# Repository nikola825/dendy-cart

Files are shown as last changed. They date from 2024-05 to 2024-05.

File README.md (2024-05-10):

# Programmable cartridge for Dendy-style consoles

Programmable PLD-based cartrige for Dendy-like consoles.

## Features
1. 1MB of SRAM for use as PRG ROM or PRG RAM
2. 1MB of SRAM for use as CHR ROM or CHR RAM
3. Atmel ATF1508 CPLD for glue logic, mapper implementation and flashing
4. LM66100 and a CR2032 battery holder to allow RAM to act as non-volatile storage
5. JTAG header for CPLD flashing

## Tooling
Makefile and linker configuration for writing programs
Pattern table generator script to generate pattern table contents from bitmaps

## Repo contents
cart - Kicad project and BOM
verilog - Verilog code for the ATF1508 CPLD
6502_development/demo_program - demo code for writing programs
6502_development/bmptransform - python script to generate pattern table contents from bmp images

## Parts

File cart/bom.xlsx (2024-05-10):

 |  |  | xxxx xxxx xxxxx xxPCS BOM (Sample Bill of Materials)
Item # | *Designator | *Qty | Manufacturer | *Mfg Part # | Description / Value | *Package/Footprint | Type | Your Instructions / Notes
1 | C1 | 1 | Don’t care | Don’t care | CAP CER 33pF 16V C0G 0603 | 0603 | SMD | Don’t care about model/manufacturer, just make sure it fits description
2 | C2, C3, C4, C5, C8, C9 | 6 | Don’t care | Don’t care | CAP CER 100nF 16V X7R 0603 | 0603 | SMD | Don’t care about model/manufacturer, just make sure it fits description
3 | C6, C7 | 2 | Don’t care | Don’t care | CAP CER 1uF 16V X7R 0805 | 0805 | SMD | Don’t care about model/manufacturer, just make sure it fits description
4 | D1, D2, D3, D4, D5, D6, D7, D8 | 8 | Foshan NationStar | NCD0603R1 | LED SMD Red 2V 20ma 0603 | 0603 | SMD
5 | R1, R4, R5, R6, R7, R8, R11, R18 | 8 | Don’t care | Don’t care | RES 10K OHM 0.1W 1% 0603 SMD | 0603 | SMD | Don’t care about model/manufacturer, just make sure it fits description
6 | R2, R3, R9, R10, R12, R13, R14, R15, R16 | 9 | Don’t care | Don’t care | RES 1K OHM 0.1W 1% 0603 SMD | 0603 | SMD | Don’t care about model/manufacturer, just make sure it fits description
7 | U1, U2 | 2 | Alliance Memory | AS6C8008-55ZIN | SRAM - Asynchronous Memory IC 8Mbit Parallel 55 ns 44-TSOP II | 44pin TSOP II | SMD
8 | U4 | 1 | Texas Instruments | SN74HCT00PWR | IC GATE NAND 4CH 2-INP 14TSSOP | 14-TSSOP | SMD
9 | U5 | 1 | Texas Instruments | SN74HCT573PWR | D-Type Transparent Latch 1 Channel 8:8 IC Tri-State 20-TSSOP | 20-TSSOP | SMD
10 | U6, U7 | 2 | Texas Instruments | LM66100DCKT | OR Controller P-Channel 1:1 SC-70-6 | 6-TSSOP, SC-88, SOT-363 | SMD
11 | U8 | 1 | Microchip Technology | ATF1508AS-7AX100 | TQFP-100(14x14) Programmable Logic Device CPLD | TQFP-100(14x14) | SMD
12 | J5/J3 | 1 | Sullins | ECC30MMVD-S189/4548247 | 60 Position Male Connector Fits Female Edgecards Gold 0.100" (2.54mm) | TH 2.54x5.08 | TH
Need a quick and accurante quote? Need an efficient production? Please read SMT Ordering Necessary Files & Info in 1 minute. Thank you very much! (https://www.pcbway.com/smt_ordering_guide.html)
Click for Instructions on How to Create a BOM (https://www.pcbway.com/blog/PCB_Assembly/How_to_Build_a_BOM__Bill_Of_Materials_.html)

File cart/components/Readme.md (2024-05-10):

## Extra symbols
Symbol packages obtained from https://ultralibrarian.com

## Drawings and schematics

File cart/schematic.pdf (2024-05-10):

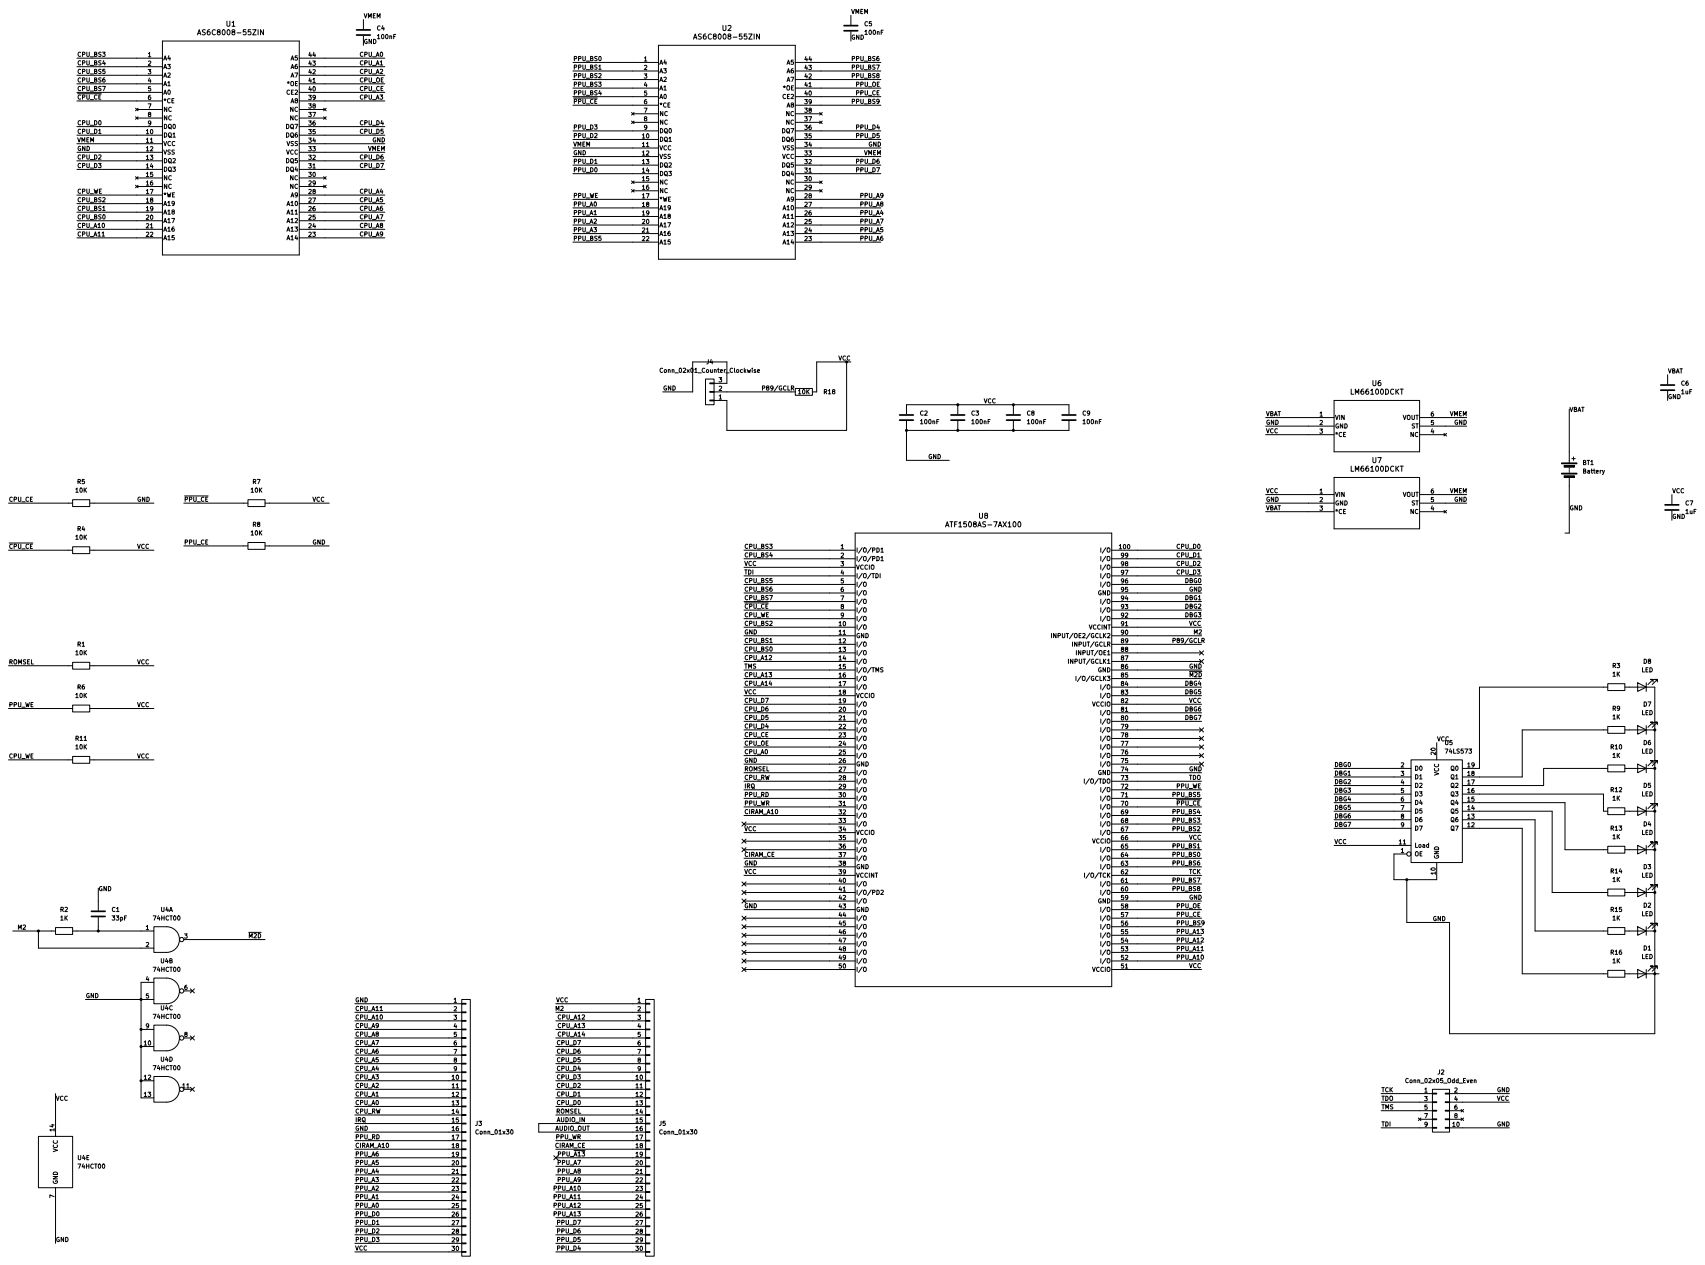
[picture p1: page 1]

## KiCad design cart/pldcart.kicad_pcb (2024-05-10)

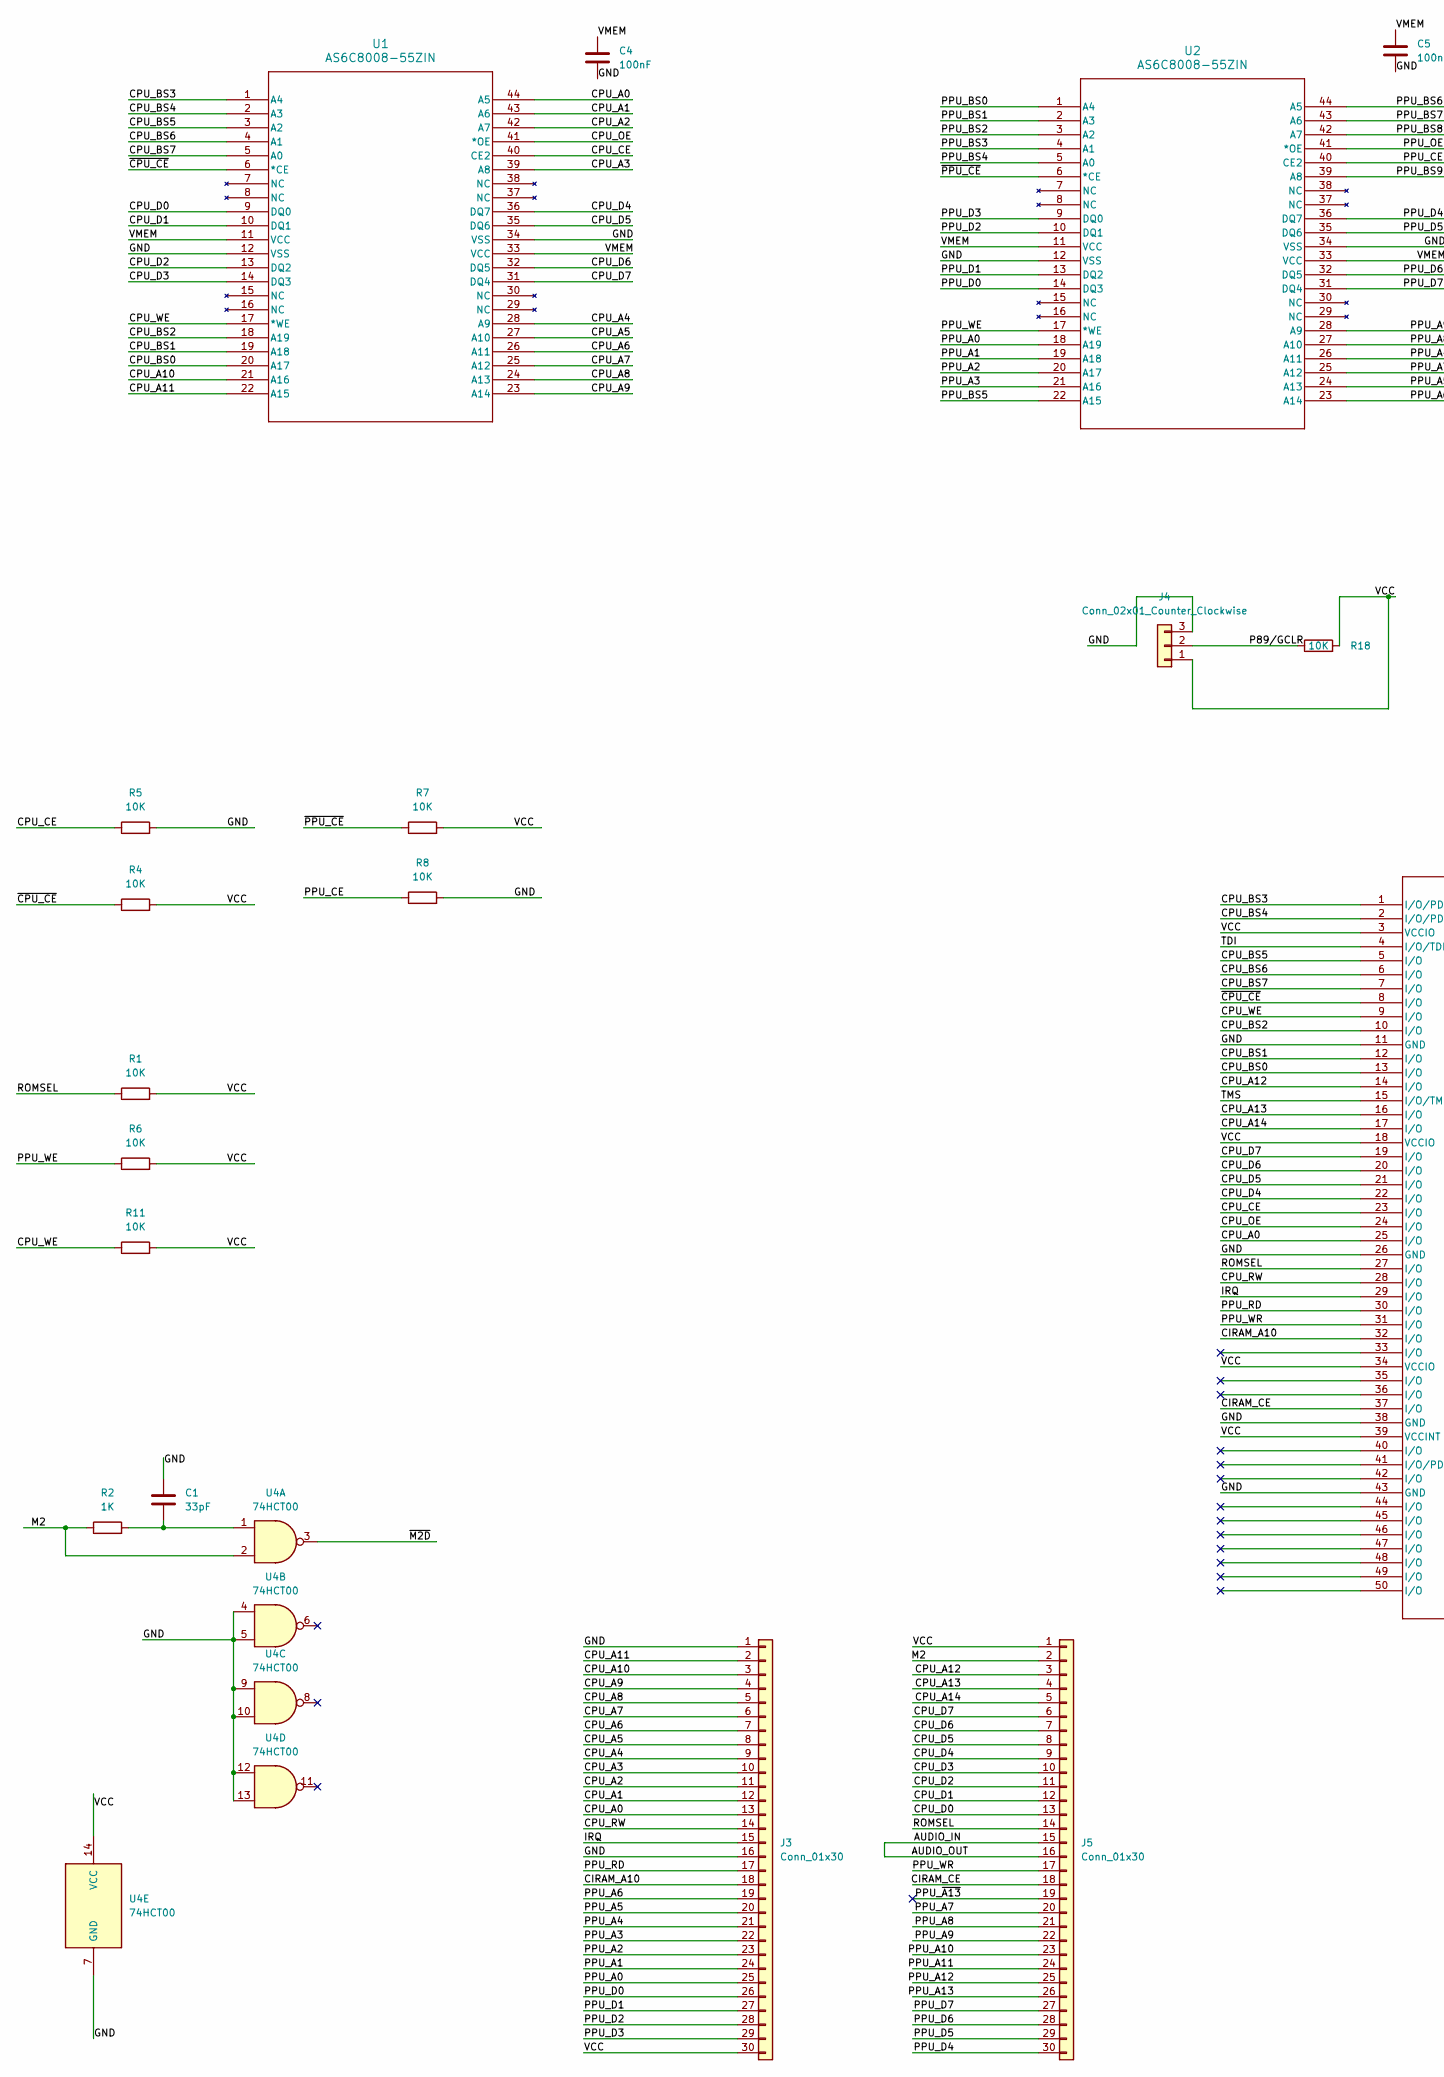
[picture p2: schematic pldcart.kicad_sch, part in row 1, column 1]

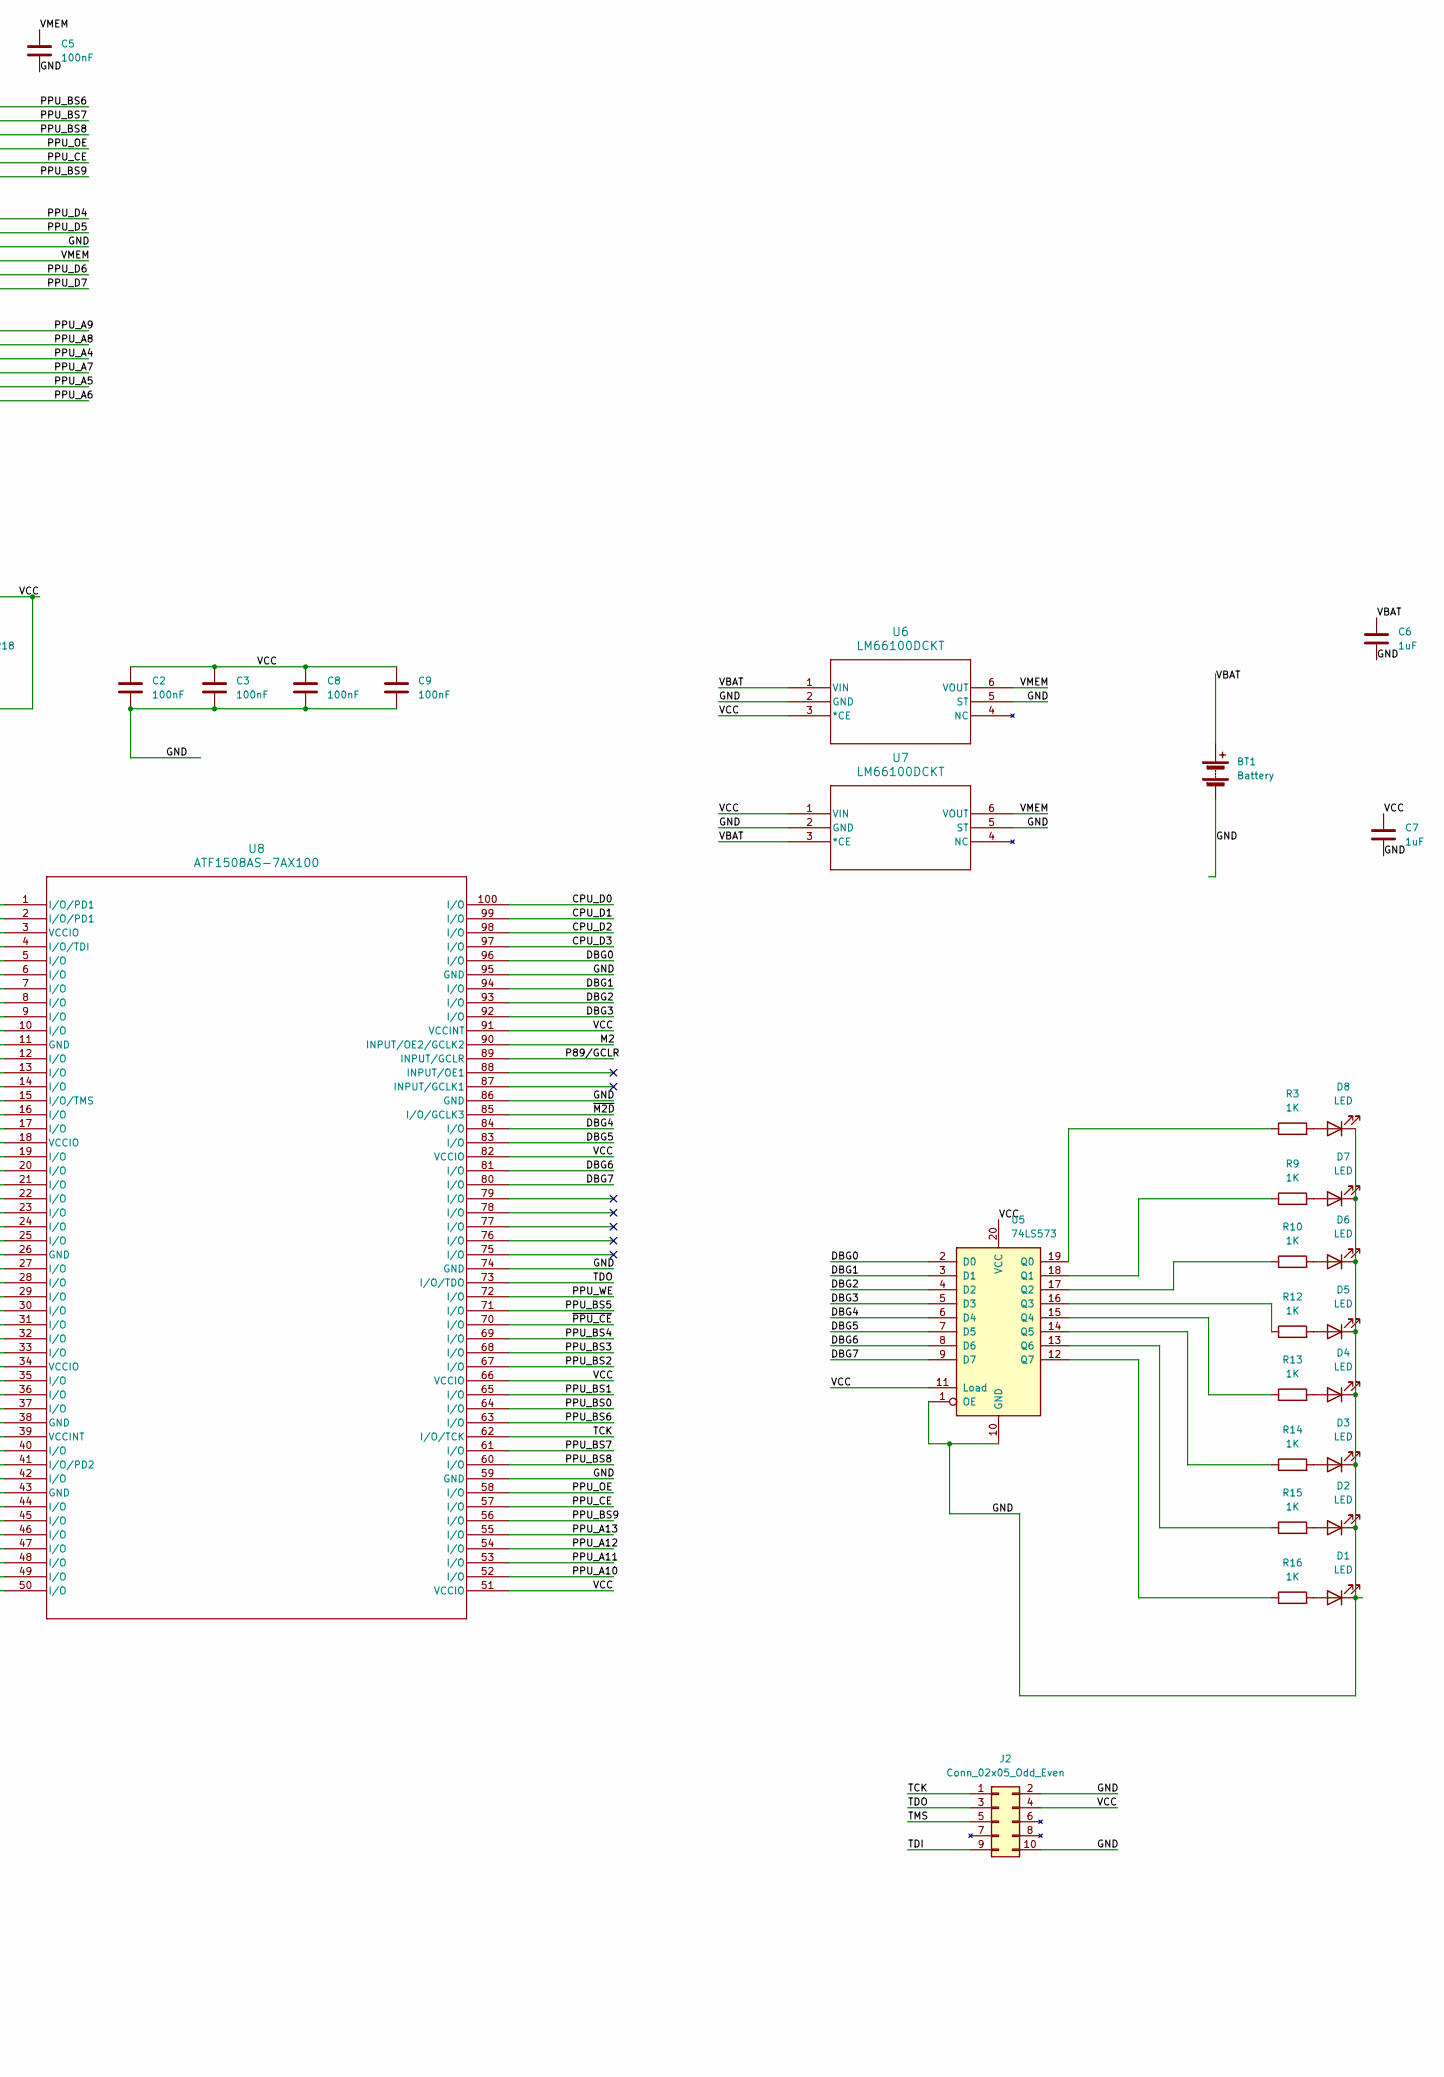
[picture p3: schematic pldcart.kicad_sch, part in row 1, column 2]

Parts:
BT1: Battery; BatteryHolder_Keystone_103_1x20mm
C1: 33pF; C_0603_1608Metric
C2, C3, C4, C5, C8, C9: 100nF; C_0603_1608Metric
C6, C7: 1uF; C_0805_2012Metric
D1, D2, D3, D4, D5, D6, D7, D8: LED; LED_0603_1608Metric
J2: Conn_02x05_Odd_Even; PinHeader_2x05_P2.54mm_Vertical
J3, J5: Conn_01x30; PinHeader_1x30_P2.54mm_Vertical
J4: Conn_02x01_Counter_Clockwise; PinHeader_1x03_P2.54mm_Vertical
R1, R4, R5, R6, R7, R8, R11, R18: 10K; R_0603_1608Metric
R2, R3, R9, R10, R12, R13, R14, R15, R16: 1K; R_0603_1608Metric
U1, U2: AS6C8008-55ZIN; TSOP-II-44_10.16x18.41mm_P0.8mm
U4: 74HCT00; TSSOP-14_4.4x5mm_P0.65mm
U5: 74LS573; TSSOP-20_4.4x6.5mm_P0.65mm
U6, U7: LM66100DCKT; SOT-363_SC-70-6
U8: ATF1508AS-7AX100; TQFP-100_14x14mm_P0.5mm

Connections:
/AUDIO_IN: J5.15, J5.16
/CIRAM_A10: J3.18, U8.32 (I/O)
/CIRAM_CE: J5.18, U8.37 (I/O)
/CPU_A0: J3.13, U1.44 (A5), U8.25 (I/O)
/CPU_A1: J3.12, U1.43 (A6)
/CPU_A2: J3.11, U1.42 (A7)
/CPU_A3: J3.10, U1.39 (A8)
/CPU_A4: J3.9, U1.28 (A9)
/CPU_A5: J3.8, U1.27 (A10)
/CPU_A6: J3.7, U1.26 (A11)
/CPU_A7: J3.6, U1.25 (A12)
/CPU_A8: J3.5, U1.24 (A13)
/CPU_A9: J3.4, U1.23 (A14)
/CPU_A10: J3.3, U1.21 (A16)
/CPU_A11: J3.2, U1.22 (A15)
/CPU_A12: J5.3, U8.14 (I/O)
/CPU_A13: J5.4, U8.16 (I/O)
/CPU_A14: J5.5, U8.17 (I/O)
/CPU_BS0: U1.20 (A17), U8.13 (I/O)
/CPU_BS1: U1.19 (A18), U8.12 (I/O)
/CPU_BS2: U1.18 (A19), U8.10 (I/O)
/CPU_BS3: U1.1 (A4), U8.1 (I/O/PD1)
/CPU_BS4: U1.2 (A3), U8.2 (I/O/PD1)
/CPU_BS5: U1.3 (A2), U8.5 (I/O)
/CPU_BS6: U1.4 (A1), U8.6 (I/O)
/CPU_BS7: U1.5 (A0), U8.7 (I/O)
/CPU_CE: R5.1, U1.40 (CE2), U8.23 (I/O)
/CPU_D0: J5.13, U1.9 (DQ0), U8.100 (I/O)
/CPU_D1: J5.12, U1.10 (DQ1), U8.99 (I/O)
/CPU_D2: J5.11, U1.13 (DQ2), U8.98 (I/O)
/CPU_D3: J5.10, U1.14 (DQ3), U8.97 (I/O)
/CPU_D4: J5.9, U1.36 (DQ7), U8.22 (I/O)
/CPU_D5: J5.8, U1.35 (DQ6), U8.21 (I/O)
/CPU_D6: J5.7, U1.32 (DQ5), U8.20 (I/O)
/CPU_D7: J5.6, U1.31 (DQ4), U8.19 (I/O)
/CPU_OE: U1.41 (*OE), U8.24 (I/O)
/CPU_RW: J3.14, U8.28 (I/O)
/CPU_WE: R11.1, U1.17 (*WE), U8.9 (I/O)
/DBG0: U5.2 (D0), U8.96 (I/O)
/DBG1: U5.3 (D1), U8.94 (I/O)
/DBG2: U5.4 (D2), U8.93 (I/O)
/DBG3: U5.5 (D3), U8.92 (I/O)
/DBG4: U5.6 (D4), U8.84 (I/O)
/DBG5: U5.7 (D5), U8.83 (I/O)
/DBG6: U5.8 (D6), U8.81 (I/O)
/DBG7: U5.9 (D7), U8.80 (I/O)
/GND: BT1.2 (-), C1.1, C2.2, C3.2, C4.2, C5.2, C6.2, C7.2, C8.2, C9.2, D1.1 (K), D2.1 (K), D3.1 (K), D4.1 (K), D5.1 (K), D6.1 (K), D7.1 (K), D8.1 (K), J2.2, J2.10, J3.1, J3.16, J4.3, R5.2, R8.2, U1.12 (VSS), U1.34 (VSS), U2.12 (VSS), U2.34 (VSS), U4.4, U4.5, U4.7 (GND), U4.9, U4.10, U4.12, U4.13, U5.1 (OE), U5.10 (GND), U6.2 (GND), U6.5 (ST), U7.2 (GND), U7.5 (ST), U8.11 (GND), U8.26 (GND), U8.38 (GND), U8.43 (GND), U8.59 (GND), U8.74 (GND), U8.86 (GND), U8.95 (GND)
/IRQ: J3.15, U8.29 (I/O)
/M2: J5.2, R2.1, U4.2, U8.90 (INPUT/OE2/GCLK2)
/P89/GCLR: J4.2, R18.1, U8.89 (INPUT/GCLR)
/PPU_A0: J3.25, U2.18 (A19)
/PPU_A1: J3.24, U2.19 (A18)
/PPU_A2: J3.23, U2.20 (A17)
/PPU_A3: J3.22, U2.21 (A16)
/PPU_A4: J3.21, U2.26 (A11)
/PPU_A5: J3.20, U2.24 (A13)
/PPU_A6: J3.19, U2.23 (A14)
/PPU_A7: J5.20, U2.25 (A12)
/PPU_A8: J5.21, U2.27 (A10)
/PPU_A9: J5.22, U2.28 (A9)
/PPU_A10: J5.23, U8.52 (I/O)
/PPU_A11: J5.24, U8.53 (I/O)
/PPU_A12: J5.25, U8.54 (I/O)
/PPU_A13: J5.26, U8.55 (I/O)
/PPU_BS0: U2.1 (A4), U8.64 (I/O)
/PPU_BS1: U2.2 (A3), U8.65 (I/O)
/PPU_BS2: U2.3 (A2), U8.67 (I/O)
/PPU_BS3: U2.4 (A1), U8.68 (I/O)
/PPU_BS4: U2.5 (A0), U8.69 (I/O)
/PPU_BS5: U2.22 (A15), U8.71 (I/O)
/PPU_BS6: U2.44 (A5), U8.63 (I/O)
/PPU_BS7: U2.43 (A6), U8.61 (I/O)
/PPU_BS8: U2.42 (A7), U8.60 (I/O)
/PPU_BS9: U2.39 (A8), U8.56 (I/O)
/PPU_CE: R8.1, U2.40 (CE2), U8.57 (I/O)
/PPU_D0: J3.26, U2.14 (DQ3)
/PPU_D1: J3.27, U2.13 (DQ2)
/PPU_D2: J3.28, U2.10 (DQ1)
/PPU_D3: J3.29, U2.9 (DQ0)
/PPU_D4: J5.30, U2.36 (DQ7)
/PPU_D5: J5.29, U2.35 (DQ6)
/PPU_D6: J5.28, U2.32 (DQ5)
/PPU_D7: J5.27, U2.31 (DQ4)
/PPU_OE: U2.41 (*OE), U8.58 (I/O)
/PPU_RD: J3.17, U8.30 (I/O)
/PPU_WE: R6.1, U2.17 (*WE), U8.72 (I/O)
/PPU_WR: J5.17, U8.31 (I/O)
/PPU_~A13: J5.19
/ROMSEL: J5.14, R1.1, U8.27 (I/O)
/TCK: J2.1, U8.62 (I/O/TCK)
/TDI: J2.9, U8.4 (I/O/TDI)
/TDO: J2.3, U8.73 (I/O/TDO)
/TMS: J2.5, U8.15 (I/O/TMS)
/VBAT: BT1.1 (+), C6.1, U6.1 (VIN), U7.3 (*CE)
/VCC: C2.1, C3.1, C7.1, C8.1, C9.1, J2.4, J3.30, J4.1, J5.1, R1.2, R4.2, R6.2, R7.2, R11.2, R18.2, U4.14 (VCC), U5.11 (Load), U5.20 (VCC), U6.3 (*CE), U7.1 (VIN), U8.3 (VCCIO), U8.18 (VCCIO), U8.34 (VCCIO), U8.39 (VCCINT), U8.51 (VCCIO), U8.66 (VCCIO), U8.82 (VCCIO), U8.91 (VCCINT)
/VMEM: C4.1, C5.1, U1.11 (VCC), U1.33 (VCC), U2.11 (VCC), U2.33 (VCC), U6.6 (VOUT), U7.6 (VOUT)
/~CPU_CE: R4.1, U1.6 (*CE), U8.8 (I/O)
/~M2D: U4.3, U8.85 (I/O/GCLK3)
/~PPU_CE: R7.1, U2.6 (*CE), U8.70 (I/O)
unnamed: C1.2, R2.2, U4.1
unnamed: D1.2 (A), R16.2
unnamed: D2.2 (A), R15.2
unnamed: D3.2 (A), R14.2
unnamed: D4.2 (A), R13.2
unnamed: D5.2 (A), R12.2
unnamed: D6.2 (A), R10.2
unnamed: D7.2 (A), R9.2
unnamed: D8.2 (A), R3.2
unnamed: R3.1, U5.19 (Q0)
unnamed: R9.1, U5.18 (Q1)
unnamed: R10.1, U5.17 (Q2)
unnamed: R12.1, U5.16 (Q3)
unnamed: R13.1, U5.15 (Q4)
unnamed: R14.1, U5.14 (Q5)
unnamed: R15.1, U5.13 (Q6)
unnamed: R16.1, U5.12 (Q7)

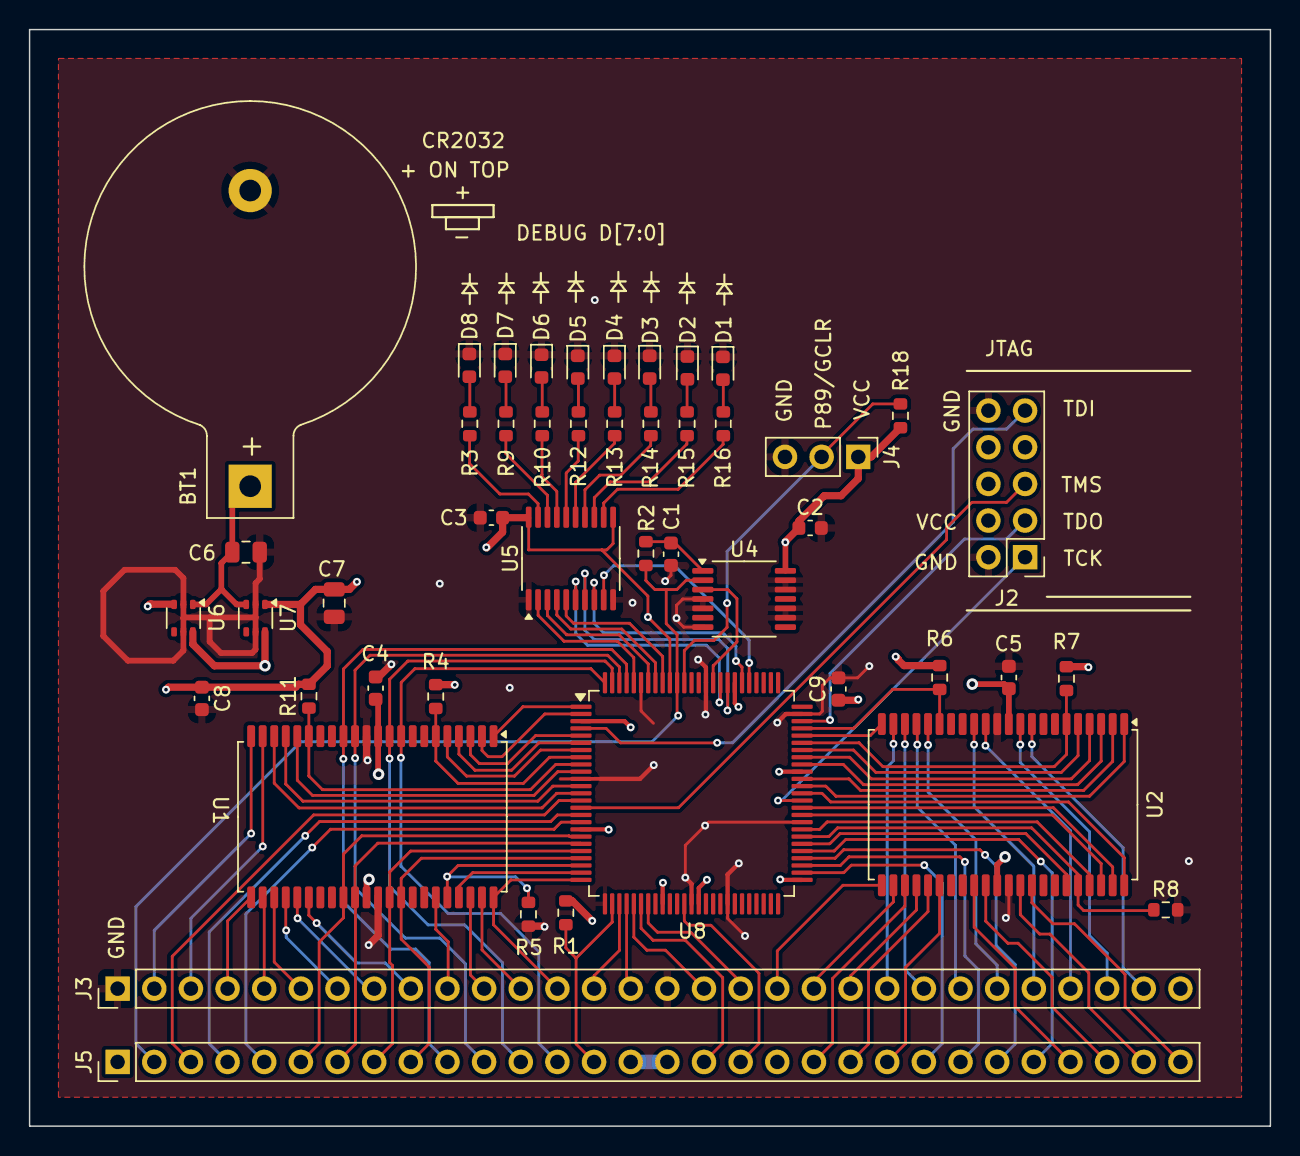
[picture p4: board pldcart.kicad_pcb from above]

Board: 4 copper layers, 86.0 x 76.0 mm, 46 parts (0 on the bottom side), 115 nets.

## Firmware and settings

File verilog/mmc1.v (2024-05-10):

reg [4:0] mmc1_control;
reg [4:0] mmc1_buffer;
reg [4:0] mmc1_ppu_bank0;
reg [4:0] mmc1_ppu_bank1;

wire chr_8k_banking;
wire prg_low_switchable;
wire prg_high_switchable;
wire prg_32k_mode;

assign chr_8k_banking = ~(mmc1_control[4]);
assign prg_low_switchable = mmc1_control[3] & mmc1_control[2];
assign prg_high_switchable = mmc1_control[3] & (~mmc1_control[2]);
assign prg_32k_mode = ~mmc1_control[3];

wire mmc1_ramsel;
assign mmc1_ramsel = ((~m2dc) & romsel) & cpu_addr[14] & cpu_addr[13];

wire mmc_cpu_select;
assign mmc_cpu_select = ~mmc1_ramsel &
                        ((prg_low_switchable & (~cpu_addr[14])) |
                         (prg_high_switchable & cpu_addr[14]) |
                         prg_32k_mode);

wire [7:0] mmc1_cpu_bs;
assign mmc1_cpu_bs = mmc_cpu_select ? (
                            prg_32k_mode ? { 2'b00, cpu_bs_reg[5:3], cpu_addr[14:12]} :
                            { 2'b00, cpu_bs_reg[5:2], cpu_addr[13:12]}
                        ) :
                        mmc1_ramsel ? { 7'b0111111, cpu_addr[12]} :
                        { 2'b00, {4{cpu_addr[14]}}, cpu_addr[13:12]};

wire mmc1_cpu_enable;
assign mmc1_cpu_enable = (~romsel) | mmc1_ramsel;

wire mmc1_cpu_write;
assign mmc1_cpu_write = mmc1_ramsel & (~cpu_rw);

wire mmc1_cpu_read;
assign mmc1_cpu_read = cpu_rw & ((~romsel) | mmc1_ramsel);

wire mmc1_vert_mirror;
assign mmc1_vert_mirror = mmc1_control[1] & (~mmc1_control[0]);

wire [9:0] mmc1_ppu_bs;
assign mmc1_ppu_bs = chr_8k_banking ? {3'b000, mmc1_ppu_bank0[4:1], ppu_addr[12:10]} :
                     ppu_addr[12] ? {3'b000, mmc1_ppu_bank1[4:0], ppu_addr[11:10]} :
                     {3'b000, mmc1_ppu_bank0[4:0], ppu_addr[11:10]};

task mmc1_init;
    begin
        mmc1_control <= 5'b11101;
        cpu_bs_reg[5:2] <= 4'b1111;
        dbg <= 8'h0e;
    end
endtask

task mmc1_special;
    begin
        if (cpu_data[7]) begin
            mmc1_buffer <= 5'b10000;
        end else if (mmc1_buffer[0]) begin
            case (cpu_addr[14:13])
                2'b00: mmc1_control <= {cpu_data[0], mmc1_buffer[4:1]};
                2'b01: mmc1_ppu_bank0 <= {cpu_data[0], mmc1_buffer[4:1]};
                2'b10: mmc1_ppu_bank1 <= {cpu_data[0], mmc1_buffer[4:1]};
                2'b11: cpu_bs_reg[5:2] <= mmc1_buffer[4:1];
            endcase
            dbg[4:0] <= {cpu_data[0], mmc1_buffer[4:1]};
            dbg[7:6] <= cpu_addr[14:13];
            mmc1_buffer <= 5'b10000;
        end else begin
            mmc1_buffer[4:0] <= {cpu_data[0], mmc1_buffer[4:1]};
        end
    end
endtask

task mmc1_reset;
    begin
        mmc1_buffer <= 5'b10000;
        mmc1_control <= 4'h0;
        mmc1_ppu_bank0 <= 5'h00;
        mmc1_ppu_bank1 <= 5'h00;
    end
endtask
